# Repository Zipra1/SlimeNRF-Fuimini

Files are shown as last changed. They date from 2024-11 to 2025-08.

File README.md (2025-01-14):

# SlimeNRF-Fuimini-PCB

Supermini-based PCB for nRF flavoured SlimeVR body trackers.

Schematic based off [SlimeVR-Tracker-nRF-PCB](https://github.com/SlimeVR/SlimeVR-Tracker-nRF-PCB)

Cat drawing on the PCB by [my amazing beatuifiul wife](https://www.tumblr.com/circlegirl?source=share)

Detailed README.md files are in folders.

## i sell these! you can find me here https://discord.gg/vpxSHmUSXH or email me at fui@macroplastics.ca
Fill out the order request form [here.](https://docs.google.com/forms/d/e/1FAIpQLScfmLpJ5HOZYNQvP2Ge38ma0vZgONCtincXcMHiBUueDEZLeg/viewform?usp=header)
Photos and user-friendly details in the spreadsheet. Website coming eventually.
Curious where prices come from? View the entire spreadsheet [here.](https://docs.google.com/spreadsheets/d/1XSO24xmqJCDWiKMqtOlyQpGnMuTRnx9r1LJr4mPH8TY/edit?usp=sharing)

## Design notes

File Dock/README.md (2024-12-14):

## Charging dock
Currently this repo only contains the files for a dock with 6 trackers. Due to technical limitations I can't provide a parametric file. I will add 5,6,7,8,9,& 10 docks later.\
If you want a dock with # of trackers that isn't included here, feel free to [contact me on discord](https://discord.gg/vpxSHmUSXH) for the files.\
Spots for rubber feet fit standard 6mm adhesive non-slip rubber feet.\
Wall mounts are for generic 1¼" drywall screws.\
Uses [Treedix USB Type-C Breakout Board](https://www.amazon.ca/gp/product/B096M2HQLK) as the USB C input. This isn't a custom PCB because only one is required per dock, it's cheaper to order these than a custom pcb in small quantities.\

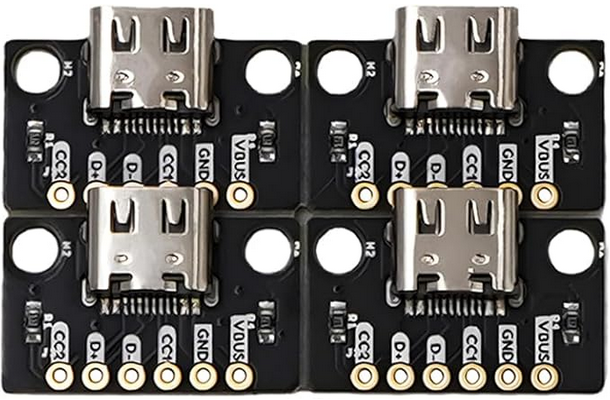
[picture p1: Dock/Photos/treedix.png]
Treedix USB Type-C Breakout Board
\

* The .3mf is for Orca Slicer. I print with a Bambu Labs P1S.

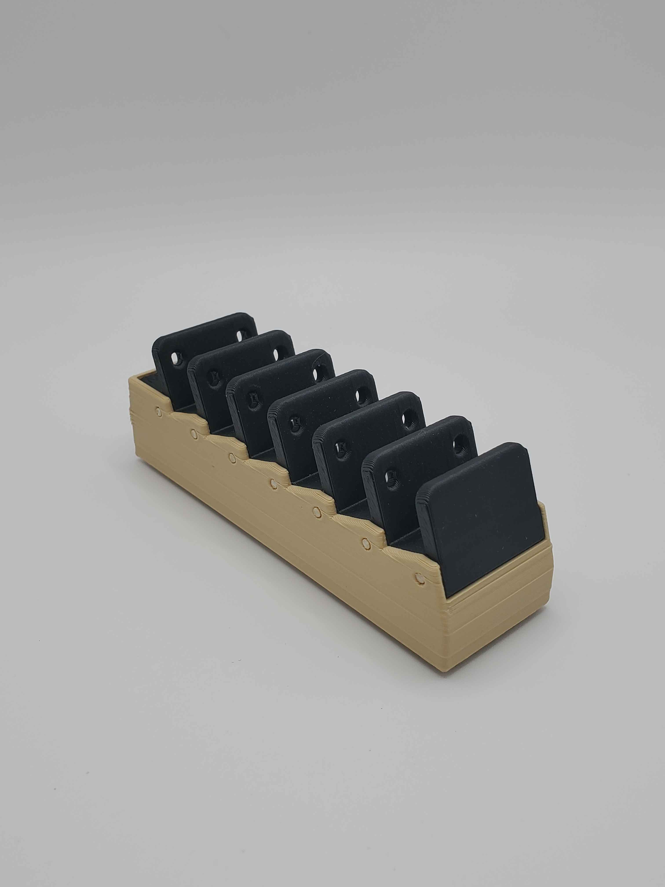
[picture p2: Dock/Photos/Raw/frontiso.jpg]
Front Photos
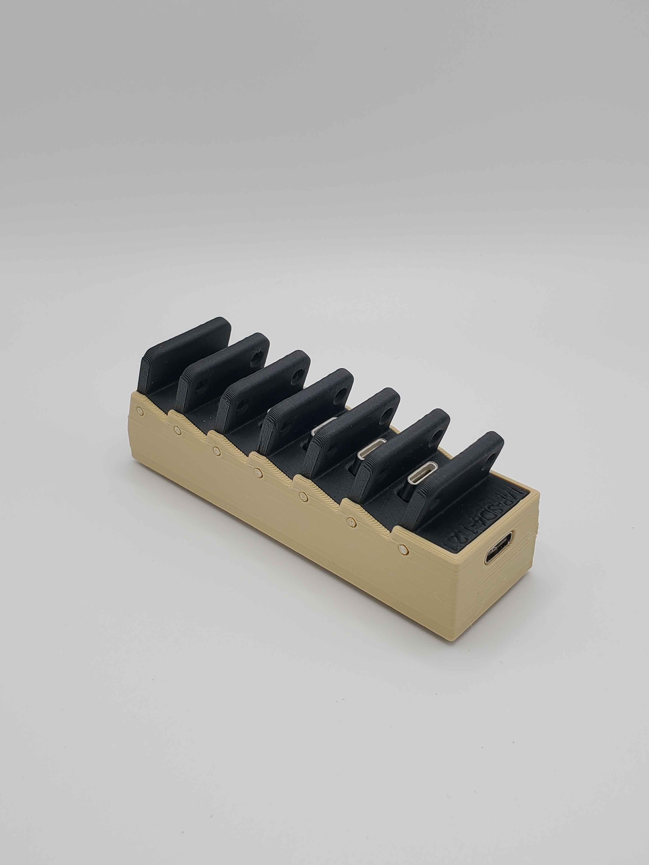
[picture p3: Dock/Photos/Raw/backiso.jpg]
Back
 \
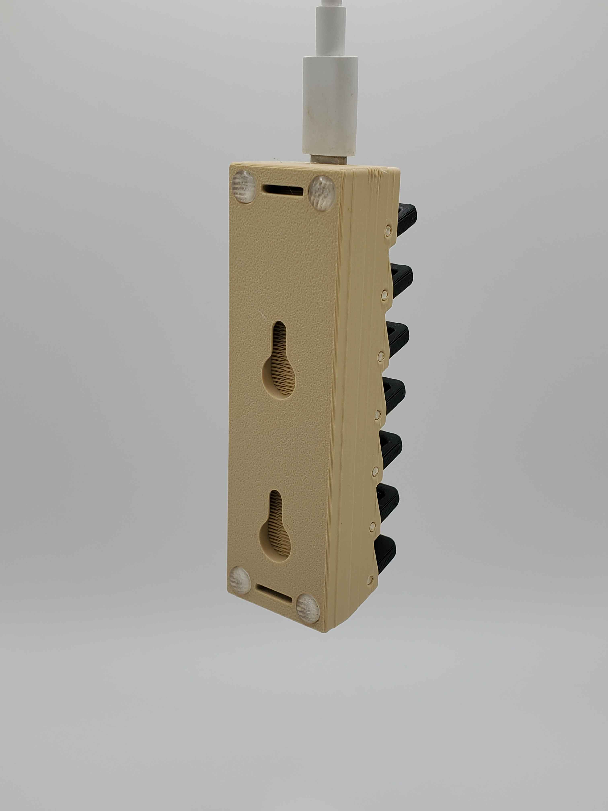
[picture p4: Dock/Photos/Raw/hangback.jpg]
Bottom
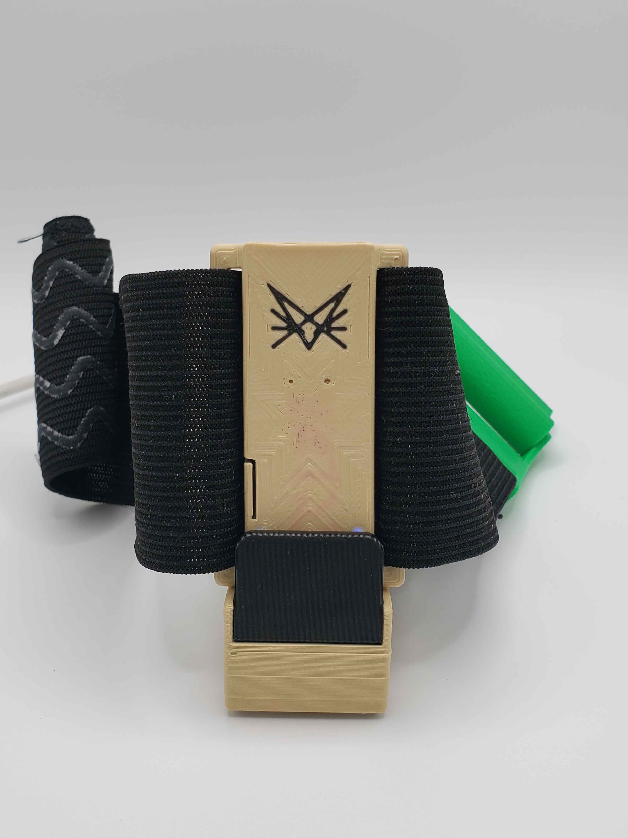
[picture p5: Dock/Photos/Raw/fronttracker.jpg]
Charging
 \

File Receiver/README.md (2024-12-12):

## This case is for the EByte nrf52840 dongle
Model number E104-BT5040U. Looks like this:
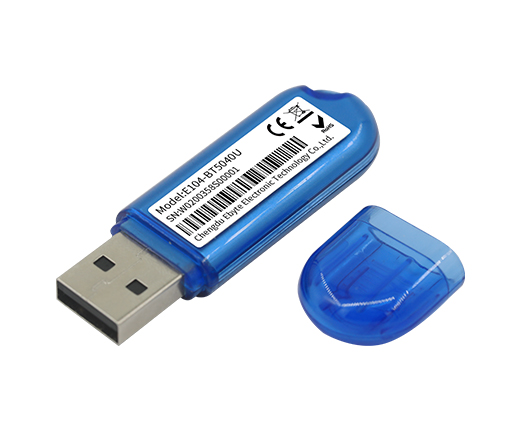
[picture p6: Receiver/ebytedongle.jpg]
ebyte dongle


New dongle case (without multimaterial) looks like this:
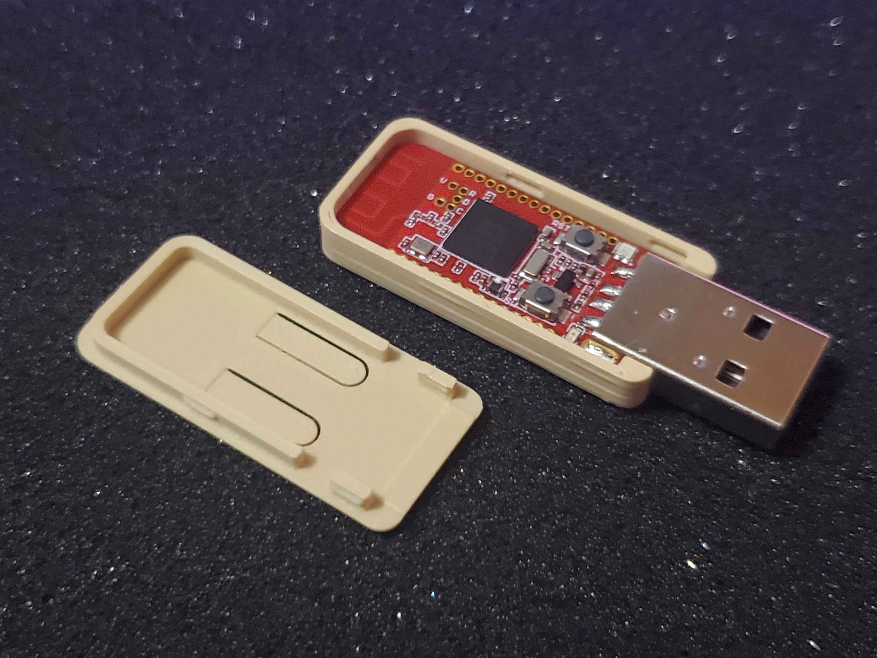
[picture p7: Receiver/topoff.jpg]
printed, top off

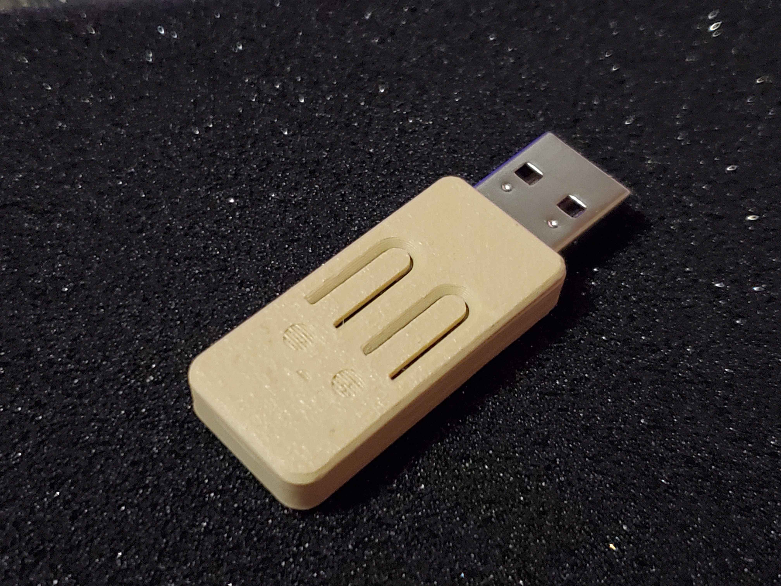
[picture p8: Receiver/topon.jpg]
printed, top on


its a bunny! :3
-# i know this folder is super disorganized. sorry :3

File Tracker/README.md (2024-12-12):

## some things to take note of!
These are pretty hard to print compared to the receiver case. I recommend looking at the .3mf file. A multi-material printer with at least 2 materials is required for the light diffuser to function.
0.12mm layer height
Layer height modifier required to print properly
Thick bridges ON
* The .3mf is for Orca Slicer. I print with a Bambu Labs P1S.

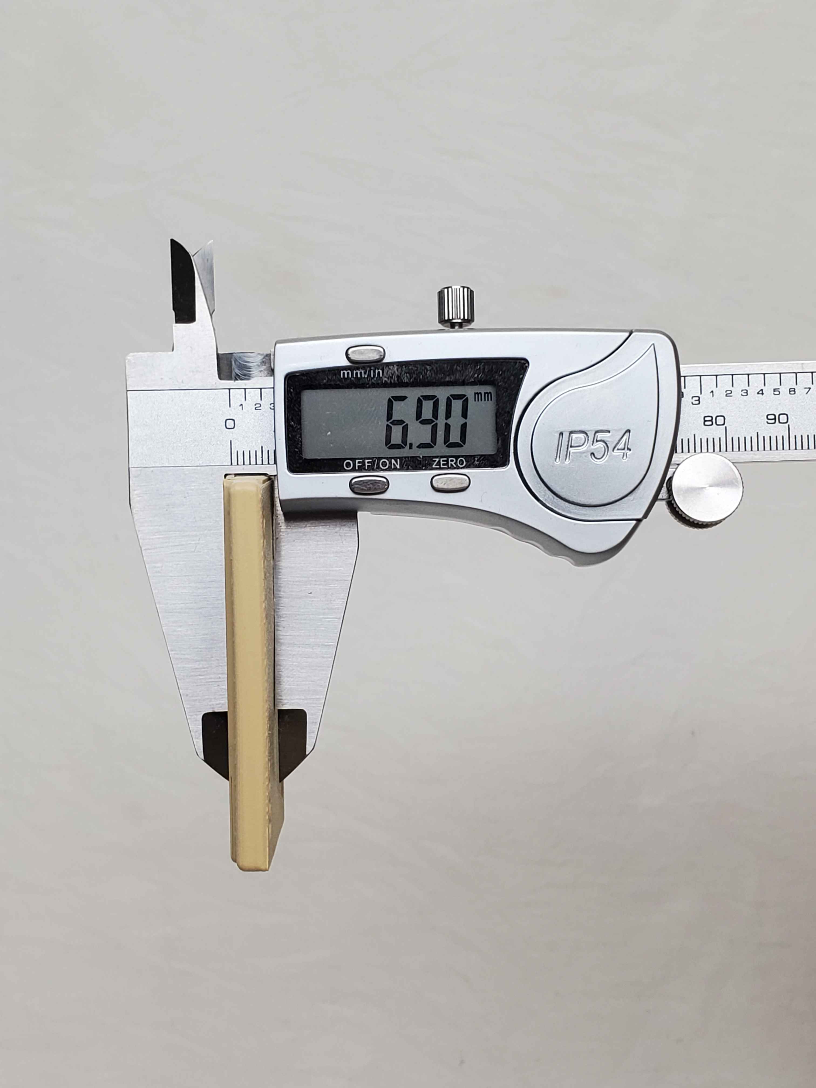
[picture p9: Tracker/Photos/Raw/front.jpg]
Front Photos

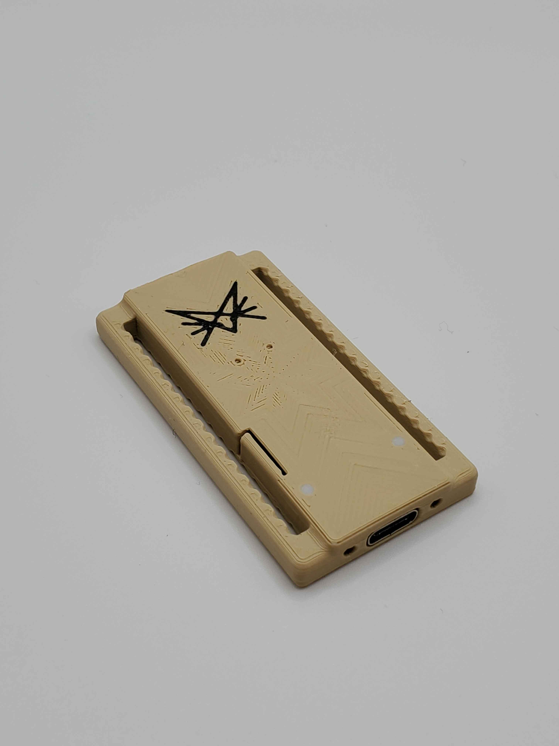
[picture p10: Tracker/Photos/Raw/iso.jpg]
Iso

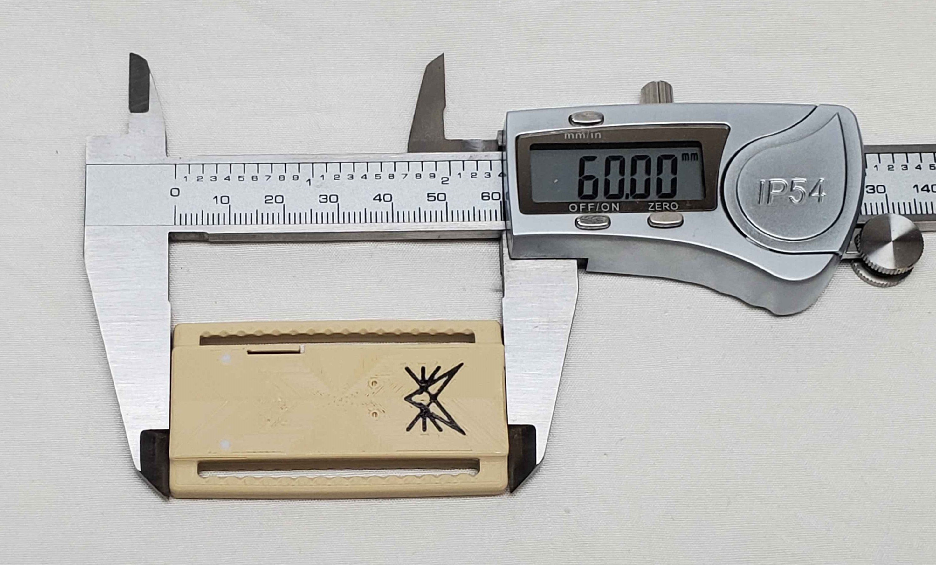
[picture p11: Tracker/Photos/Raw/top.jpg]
Top

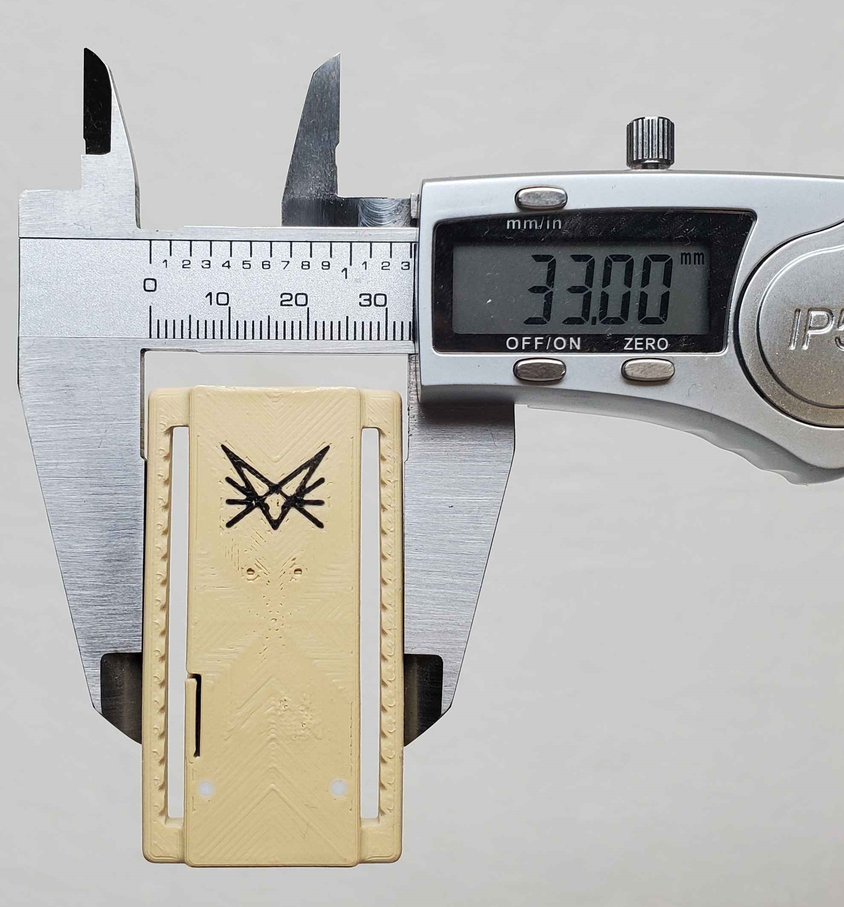
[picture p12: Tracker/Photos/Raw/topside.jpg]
Top side measurement


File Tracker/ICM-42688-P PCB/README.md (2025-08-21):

# This is currently NON-FUNCTIONAL
It is in the midst of an update to SPI, as well as some extra features. Please check out Commit `f3380db` for the currently functional version.

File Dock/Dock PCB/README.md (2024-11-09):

# Dock
The dock uses a "treedix" USB C breakout board instead of a custom PCB for the USB C, as I am not planning to make a large enough volume to justify having a separate b oard with USB C.

The dock is made of several individual PCB's so that they can be slanted in the dock, making it better for mounting on wall (even though really they'd be fine, it looks nicer like that)

Design is not final. I might abandon the slant idea if it's not worth it.

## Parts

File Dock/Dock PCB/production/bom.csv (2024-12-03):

Designator | Footprint | Quantity | Value | LCSC Part #
J1, J2 | PinHeader_1x04_P2.54mm_Vertical | 2 | DNP
U1 | Treedix USB Type-C | 1 | DNP
U2 | YTC-TC16S-128 | 1 | YTC-TC16S-128

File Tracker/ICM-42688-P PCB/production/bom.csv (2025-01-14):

Designator | Footprint | Quantity | Value | LCSC Part #
C2 | 0402 | 1 | 1uF | C14663
C3 | 0402 | 1 | 10nF | C14663
C4, C8 | 0402 | 2 | 100nF | C14663
C5 | 0402 | 1 | 10uF | C14663
C7 | 0402 | 1 | 2.2uF | C14663
R1, R2 | 0402 | 2 | 10k | C23162
R5 | 0402 | 1 | 200k | C23162
S1 | GT-TC020B-H035-L05 | 1 | GT-TC020B-H035-L05
TP1, TP2 | 2_4-1.5_3.5_1 | 2 | BCon
U2 | ICM-42688-P | 1 | ICM-42688-P
U3 | MMC5983MA | 1 | MMC5983MA
U4 | K3-1295S-E1 | 1 | K3-1295S-E1
X1 | OK252032.768KJBA4SL | 1 | ~

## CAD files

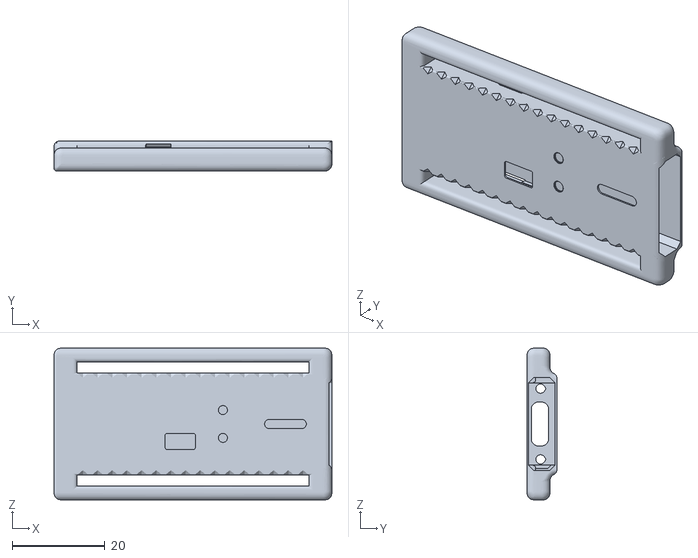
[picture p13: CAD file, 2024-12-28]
Tracker/3D Models/Main Body.STL
60.0 x 6.48 x 32.8

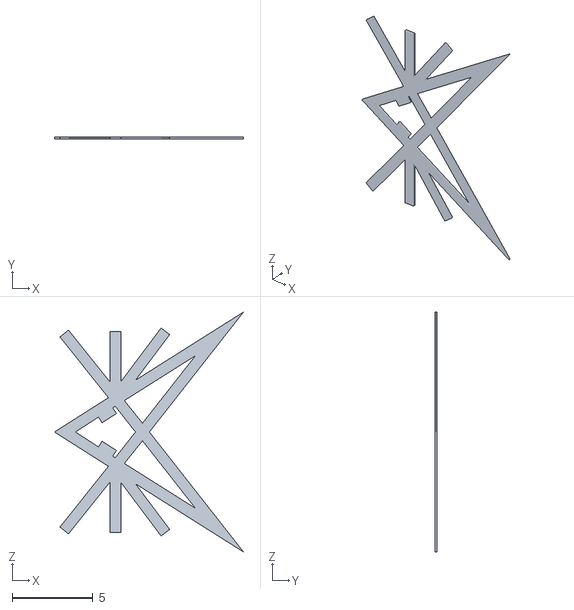
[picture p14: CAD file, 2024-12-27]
Tracker/3D Models/Main Body_Logo.STL
11.7 x 0.12 x 14.8

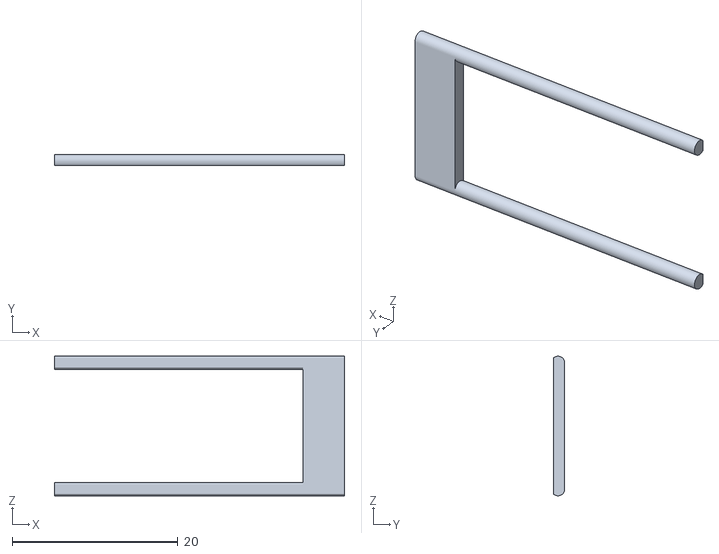
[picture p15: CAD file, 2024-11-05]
Tracker/3D Models/Disassembly tool.STL
35.0 x 1.37 x 16.9

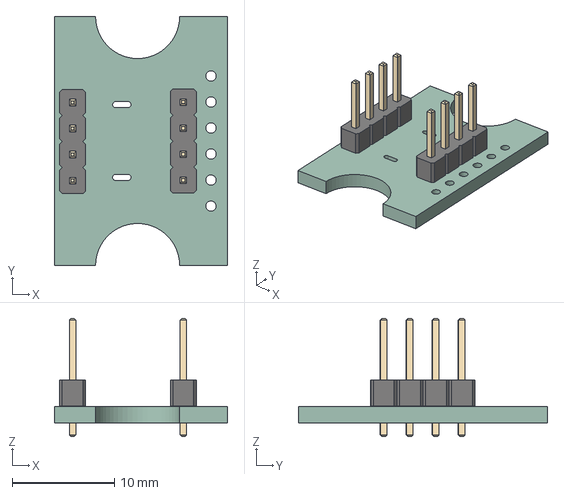
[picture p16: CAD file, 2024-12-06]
Dock/Dock PCB/SlimeV3-Dock.step
16.9 x 24.3 x 11.5 mm
PinHeader_1x04_P254mm_Vertical x 2
SlimeV3-Dock_PCB

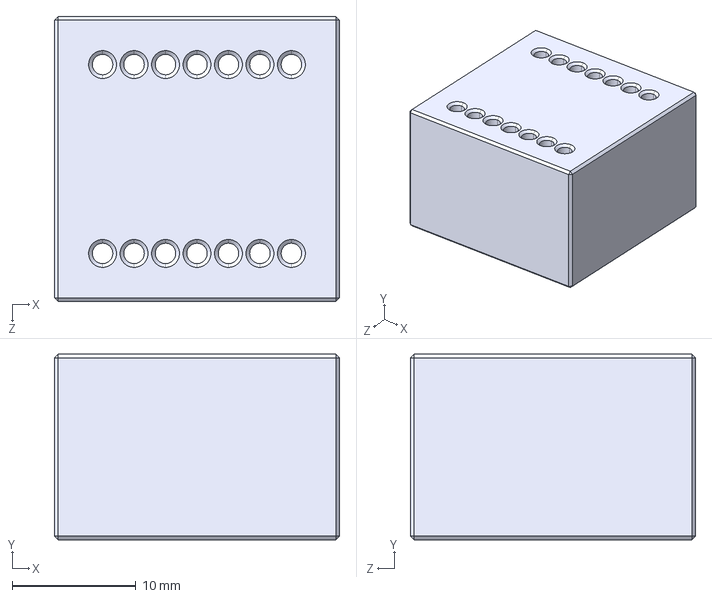
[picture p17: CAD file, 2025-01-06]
Jigs/Pogo pin testing block.STEP
23.0 x 15.0 x 23.0 mm

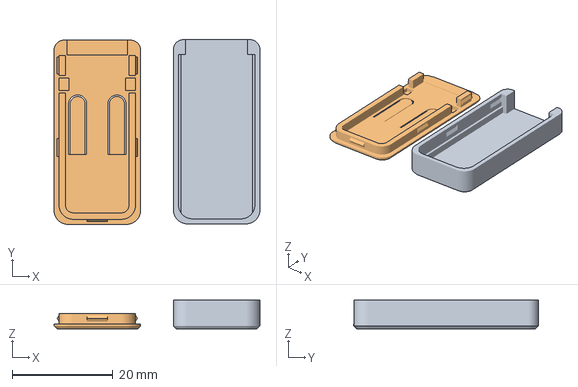
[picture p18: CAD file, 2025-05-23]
Receiver/ebyte.3mf
40.9 x 36.7 x 5.75 mm
nRF52840 EByte Button Case Bottom.STEP
nRF52840 EByte Button Case Top.STEP

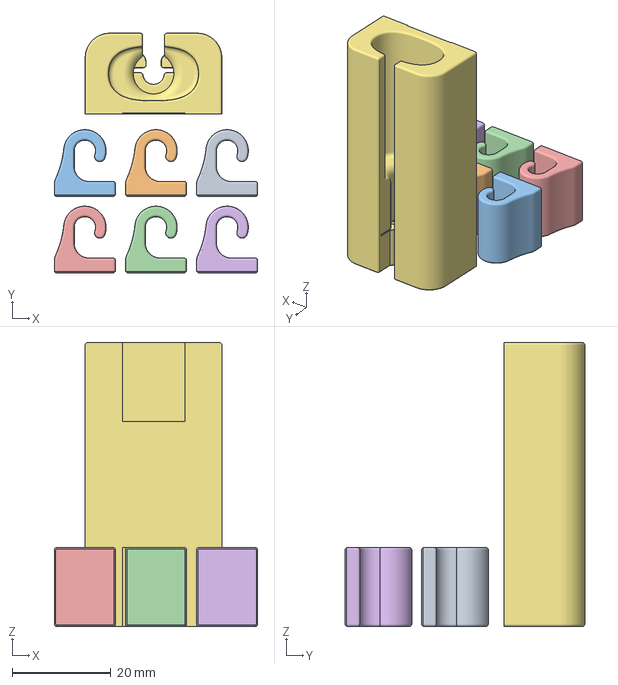
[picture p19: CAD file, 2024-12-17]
Receiver/Extension cable/Hook+mount.3mf
41.2 x 48.5 x 57.5 mm
Cable hook.STEP x 6
Ceiling mount.STEP

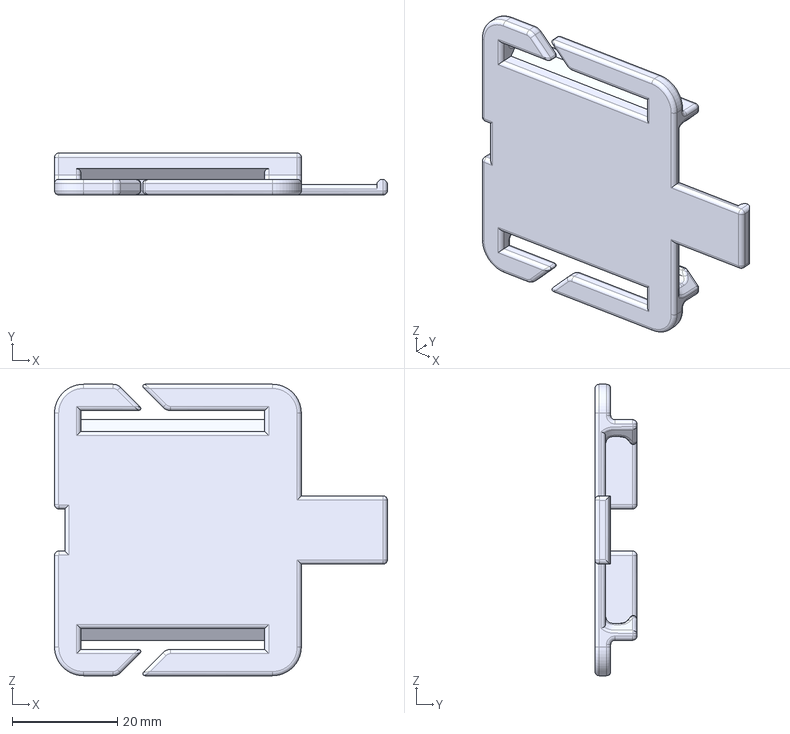
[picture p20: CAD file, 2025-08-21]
Straps/Chesty Mount Alt.STEP
63.4 x 8.00 x 55.5 mm

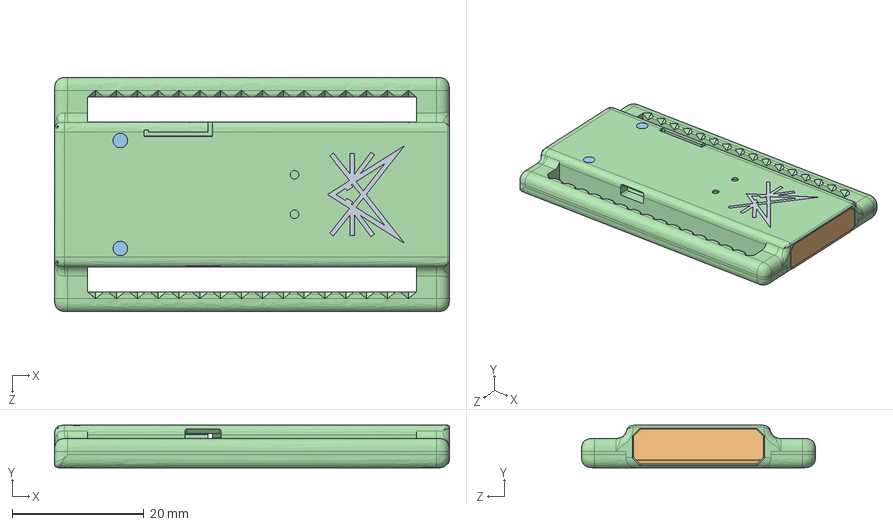
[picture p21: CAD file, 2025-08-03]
Tracker/3D Models/FuiminiCase.STEP
60.0 x 6.48 x 35.6 mm

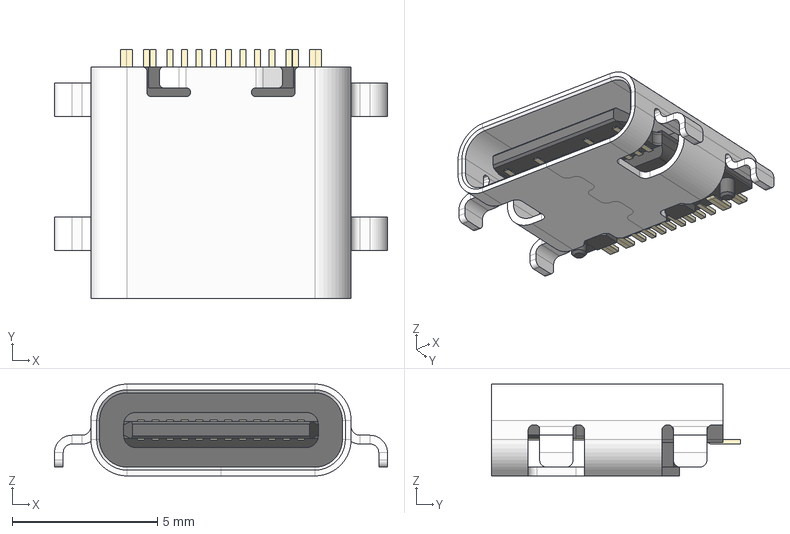
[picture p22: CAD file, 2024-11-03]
Tracker/ICM-42688-P PCB/HRO TYPE-C-31-M-14.step
11.5 x 8.56 x 3.16 mm
Shroud
Plastic Body & Connector

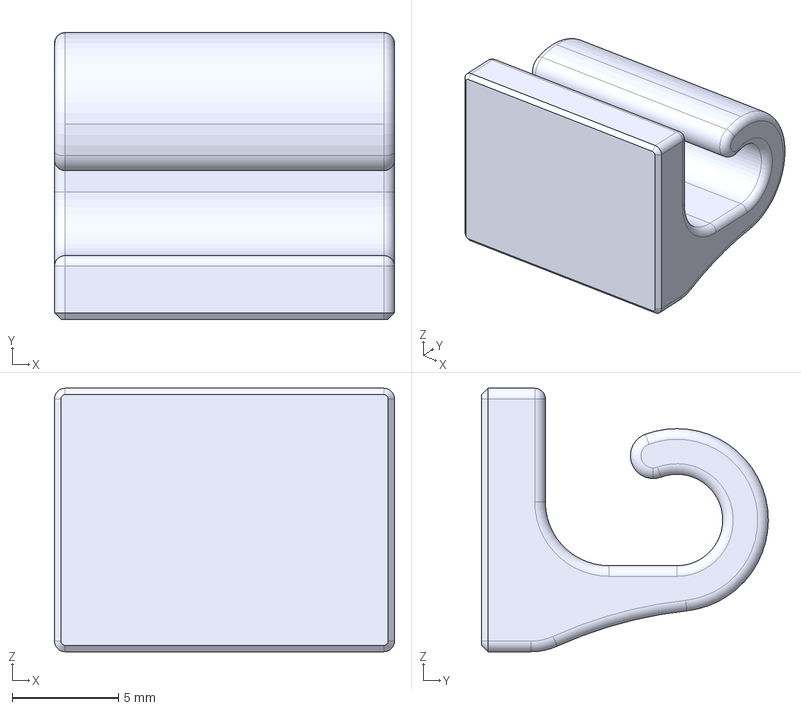
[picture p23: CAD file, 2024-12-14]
Receiver/Extension cable/Cable hook.STEP
16.0 x 13.5 x 12.4 mm

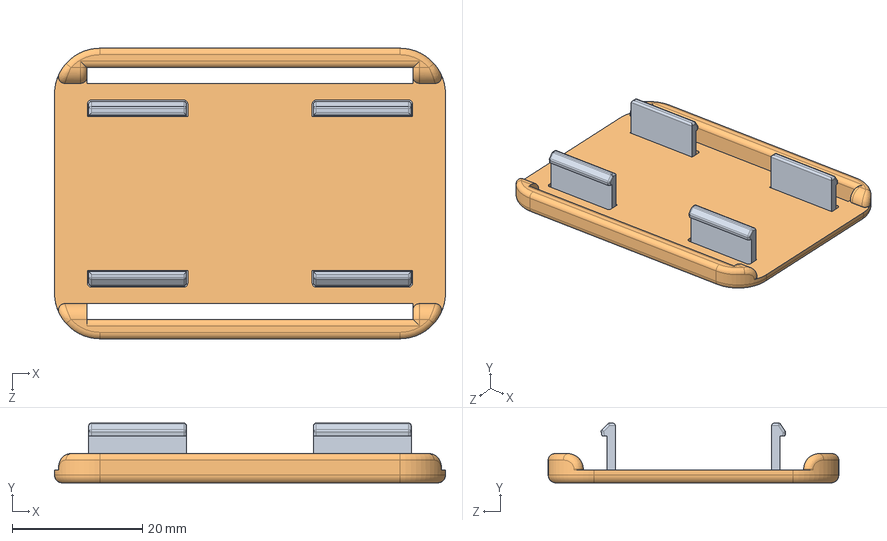
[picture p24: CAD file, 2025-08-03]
Straps/Chest clip.STEP
60.0 x 9.18 x 44.6 mm

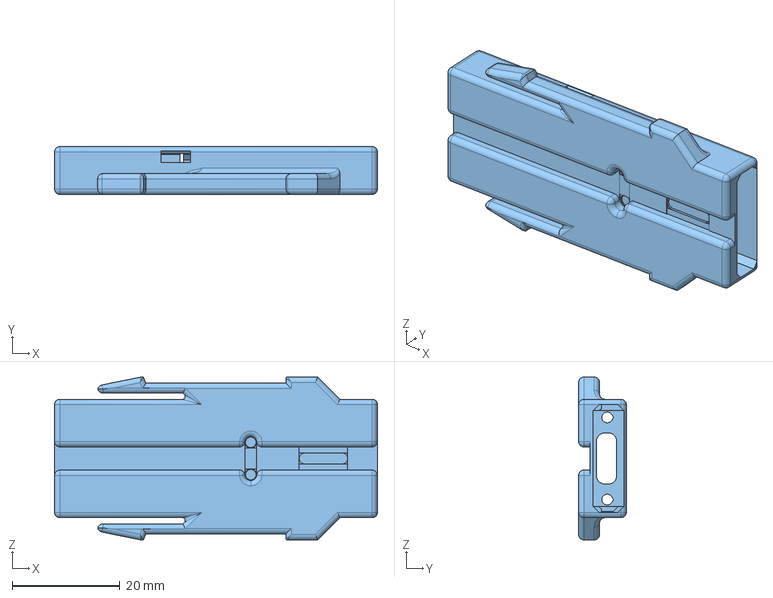
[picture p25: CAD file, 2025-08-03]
Tracker/3D Models/FuiminiCase-GoPro.STEP
60.0 x 8.88 x 30.3 mm

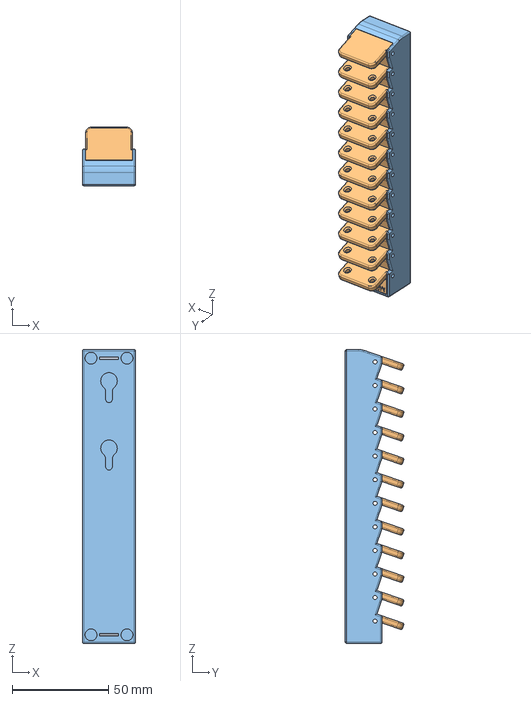
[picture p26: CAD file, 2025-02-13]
Dock/3D Models/SV4 dock (11).STEP
27.7 x 30.5 x 152.7 mm

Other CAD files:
Receiver/Extension cable/Ceiling mount.STEP
Straps/Cam Lock Shoulder Strap.STEP
Tracker/3D Models/Case.3mf
Dock/3D Models/SV4 dock (10).STEP
Dock/3D Models/SV4 dock (5).STEP
Dock/3D Models/SV4 dock (7).STEP
Dock/3D Models/SV4 dock (8).STEP
Dock/3D Models/SV4 dock.3mf
Dock/3D Models/SV4 dock.STEP
Jigs/Pogo pin testing block.3mf
Receiver/nRF52840 EByte Button Case Bottom.STEP
Receiver/nRF52840 EByte Button Case Top.STEP
Straps/Cam Lock Shoulder Strap Back Triangle.STEP
Straps/Chesty Mount.STEP
Straps/Velcro strap quick release.3mf
Straps/Velcro strap quick release.STEP
Tracker/3D Models/Calibration Jig.STEP
Tracker/3D Models/Debug Jig.STL
Tracker/3D Models/End Cap.STL
Tracker/3D Models/Light Diffuser.STL
Tracker/3D Models/Pin cutting jig.STL
Tracker/3D Models/USB_type_C_smd_24p.stp

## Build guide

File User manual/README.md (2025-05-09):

## Most human-readable version is in the Individual Pages folder.
The PDF files are a printable booklet, for printers that can only print on one side and have the paper feed on the back.
The booklet pdf's are made using https://online2pdf.com/create-booklet-flipbook

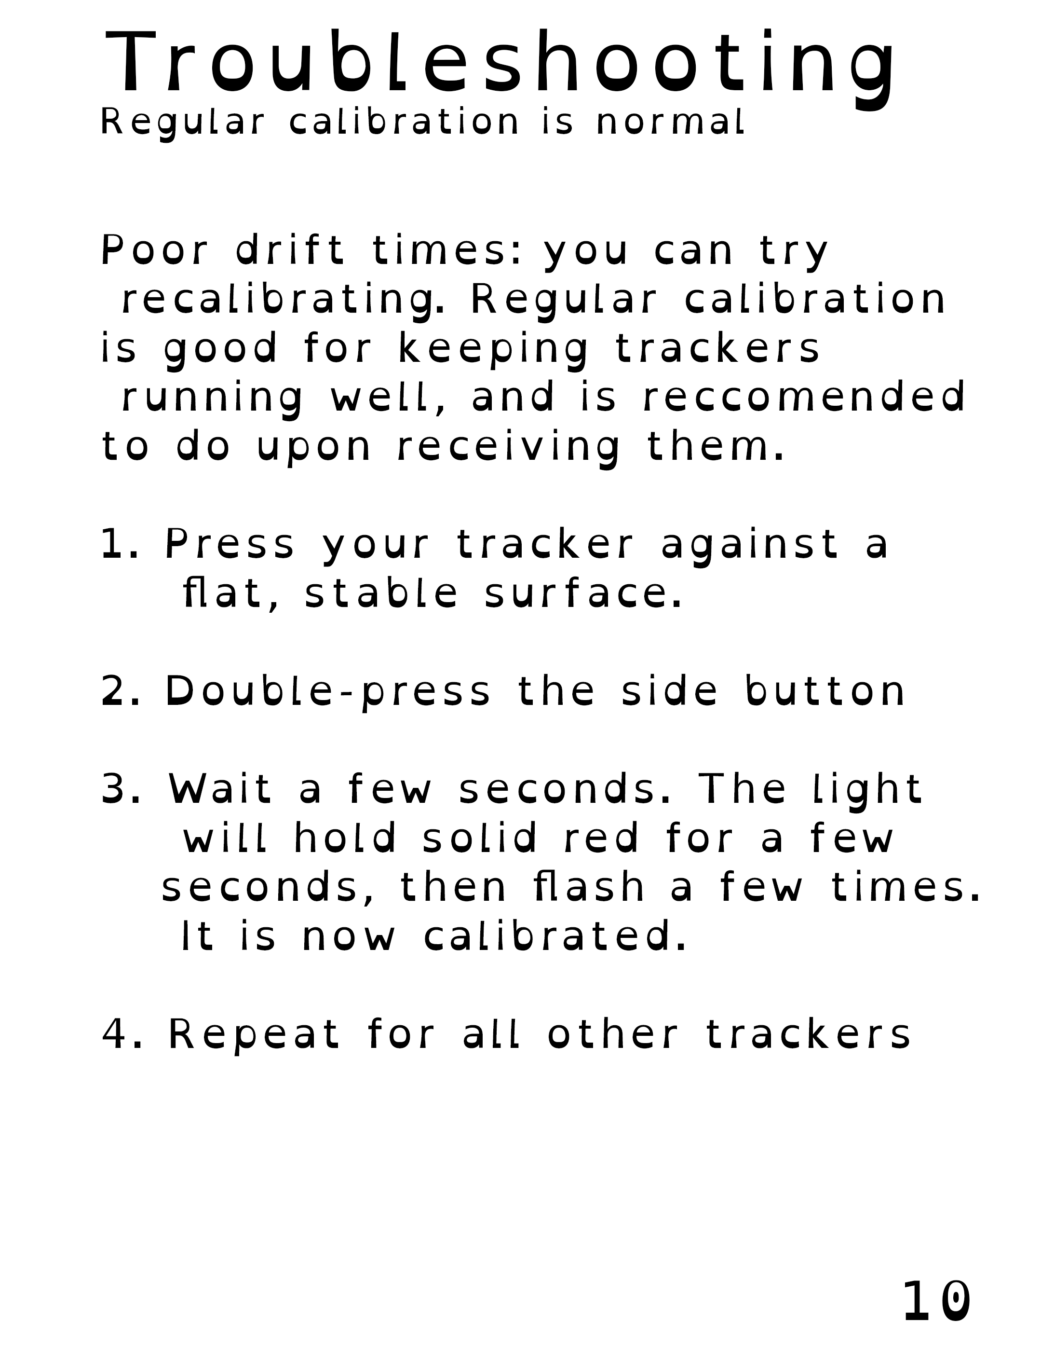
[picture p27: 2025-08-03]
User manual/Individual pages/L.png

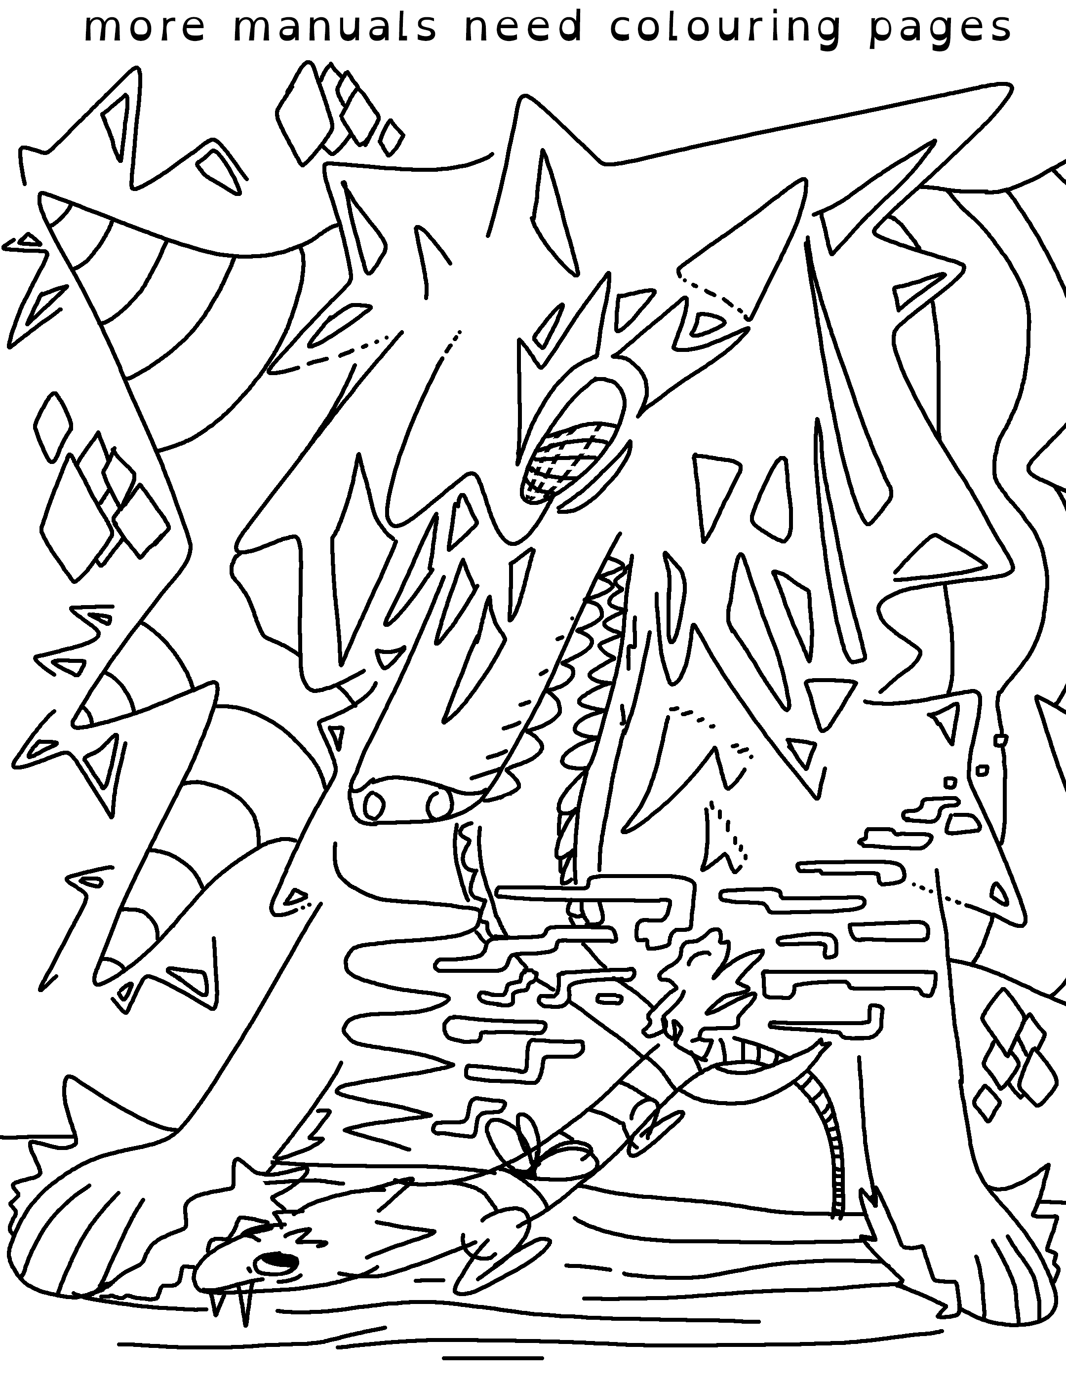
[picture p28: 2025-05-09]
User manual/Individual pages/S.png

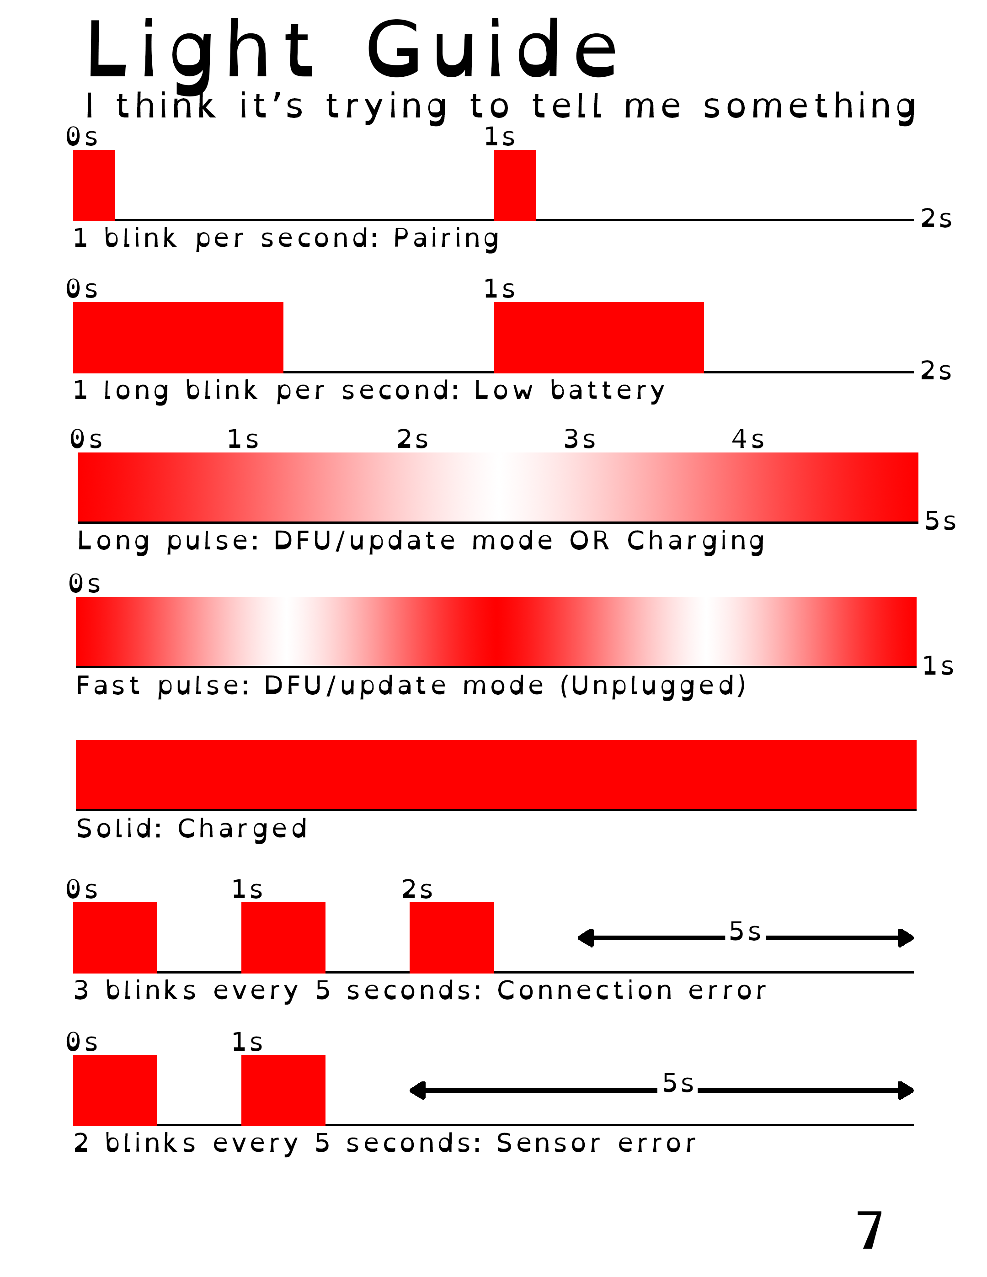
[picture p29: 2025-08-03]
User manual/Individual pages/I.png

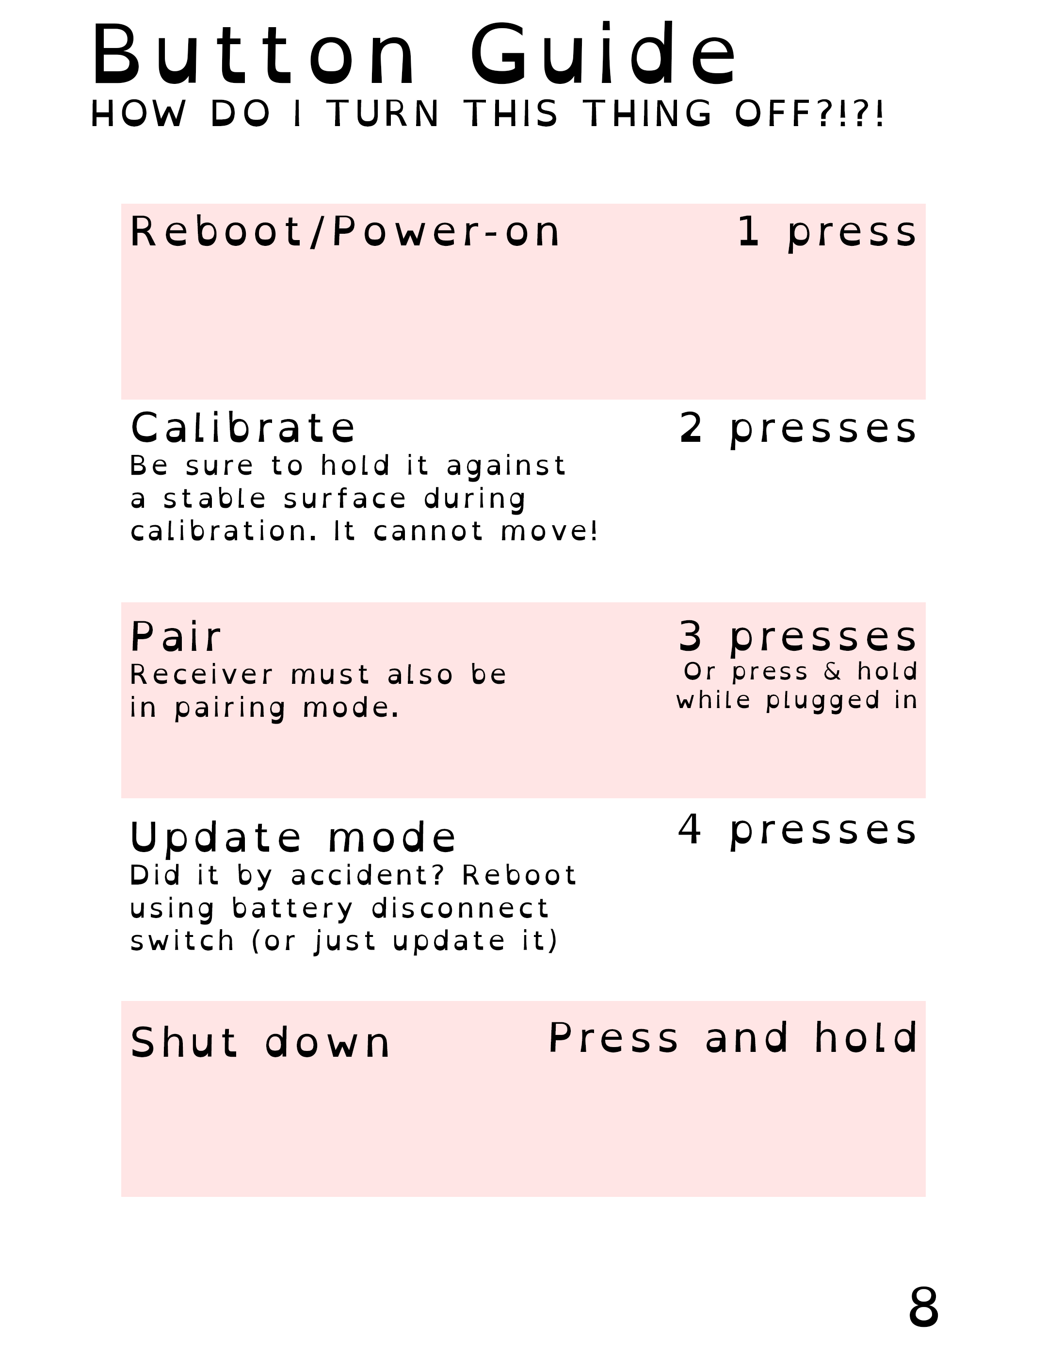
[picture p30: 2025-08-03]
User manual/Individual pages/J.png

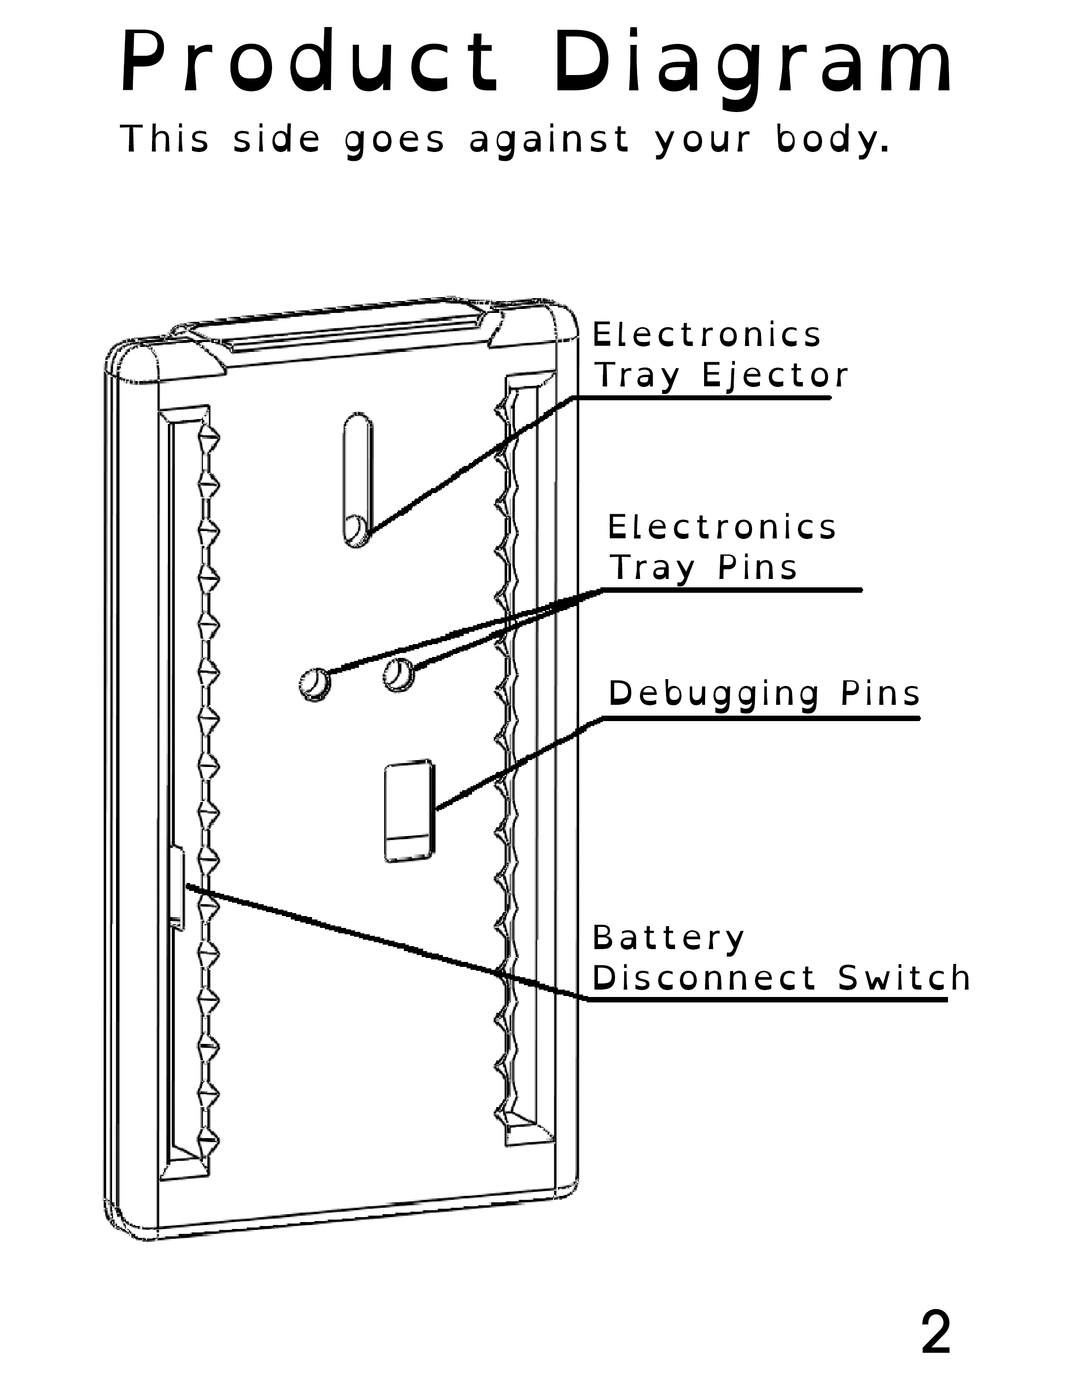
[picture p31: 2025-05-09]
User manual/Individual pages/D.png

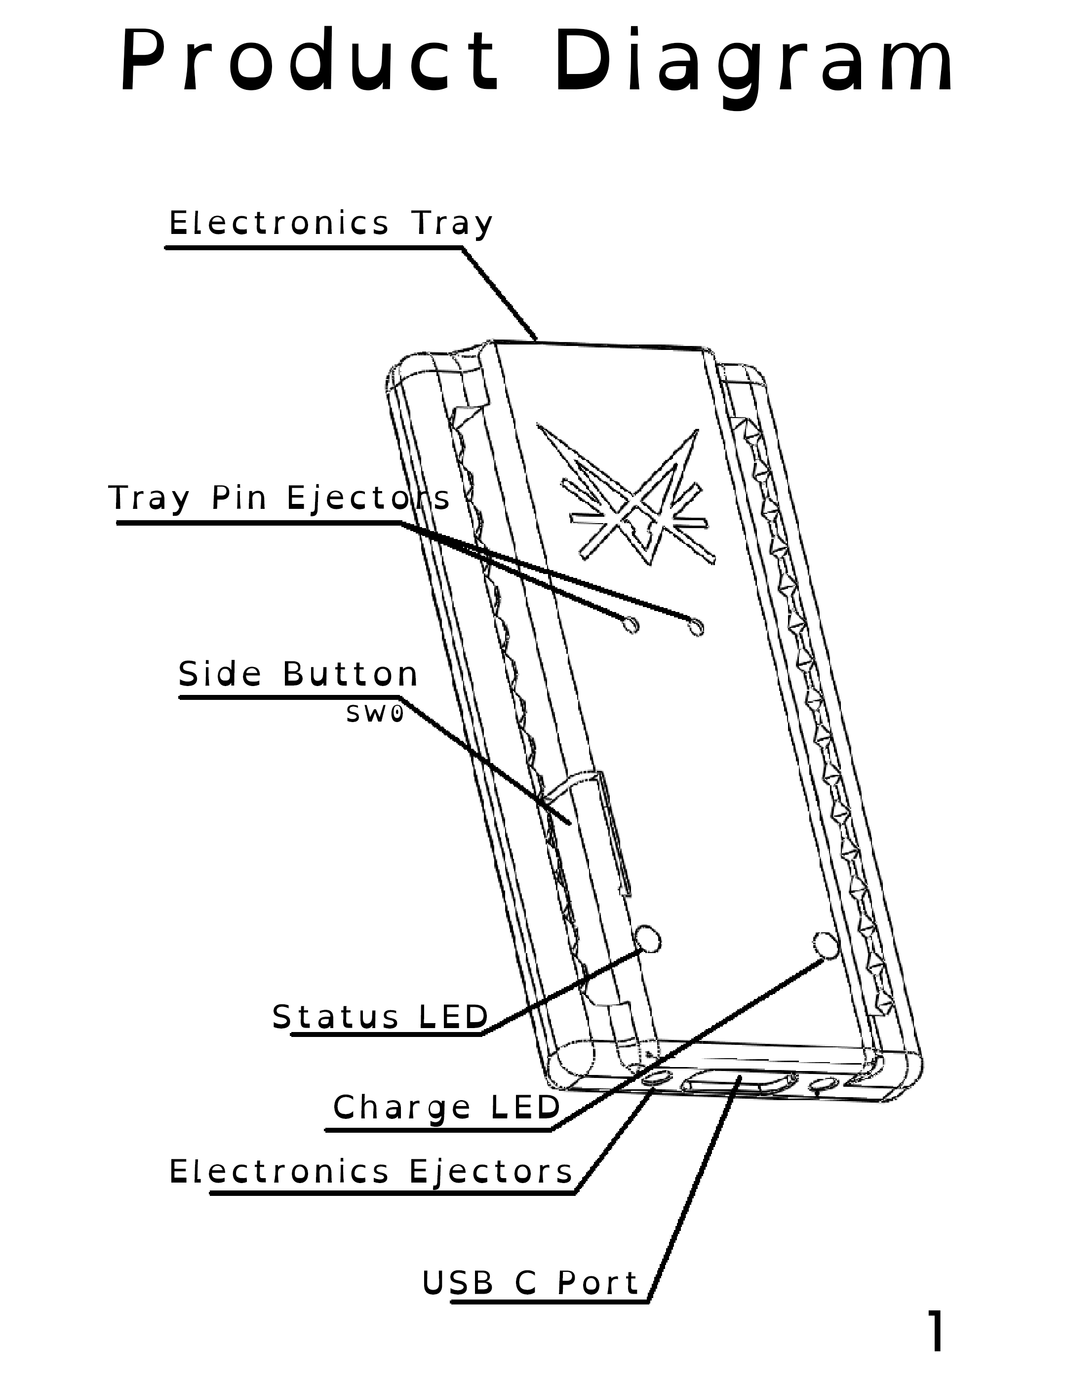
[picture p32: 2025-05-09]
User manual/Individual pages/C.png

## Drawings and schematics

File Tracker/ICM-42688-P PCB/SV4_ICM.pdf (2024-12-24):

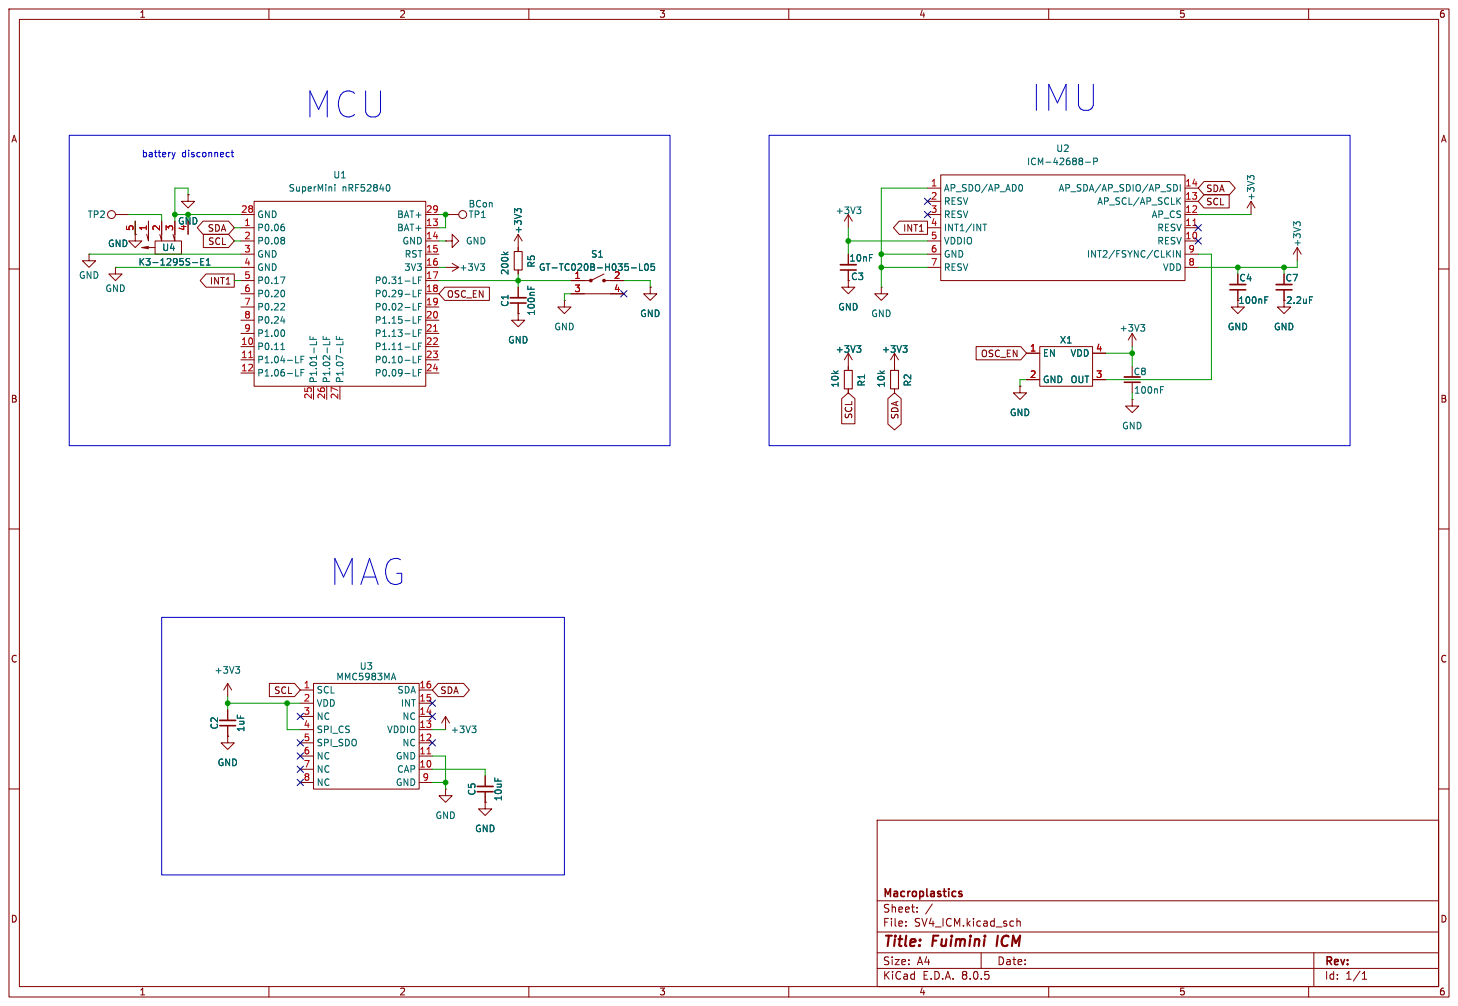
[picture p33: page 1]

Id: 1/1 Title: Fuimini ICM

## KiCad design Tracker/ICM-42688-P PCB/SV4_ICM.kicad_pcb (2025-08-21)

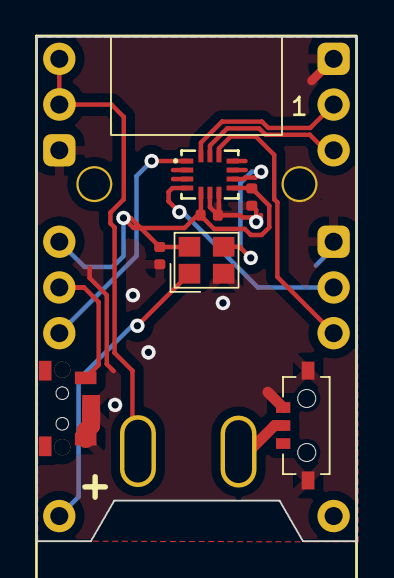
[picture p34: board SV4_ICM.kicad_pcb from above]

Board: 2 copper layers, 17.8 x 28.0 mm, 10 parts (0 on the bottom side), 12 nets.

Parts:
C3, C4, C8: 100nF; C_0402_1005Metric
S1: GT-TC020B-H035-L05
TP1, TP2: BCon; 2_4-1.5_3.5_1
U1: SuperMini nRF52840; SuperMini_nRF52840_AH_USBdn
U2: ICM-42688-P
U4: K3-1295S-E1
X1: OK252032.768KJBA4SL

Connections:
+3V3: C3.2, C4.2, C8.2, U1.16 (3V3), U2.5 (VDDIO), U2.8 (VDD), X1.4 (VDD)
CLK: U2.9 (INT2/FSYNC/CLKIN), X1.3 (OUT)
CS: U1.6 (P0.20), U2.12 (AP_CS)
GND: C3.1, C4.1, C8.1, S1.2, S1.3, U1.4 (GND), U1.14 (GND), U1.28 (GND), U2.6 (GND), U2.7 (RESV), U4.3, U4.4, U4.5, X1.2 (GND)
INT1: U1.5 (P0.17), U2.4 (INT1/INT)
unnamed: TP1.1, U1.13 (BAT+), U1.29 (BAT+)
unnamed: TP2.1, U4.2
unnamed: S1.1, U1.17 (P0.31-LF)
OSC_EN: U1.22 (P1.11-LF), X1.1 (EN)
SCL: U1.2 (P0.08), U2.13 (AP_SCL/AP_SCLK)
SDA: U1.1 (P0.06), U2.14 (AP_SDA/AP_SDIO/AP_SDI)
SDO: U1.18 (P0.29-LF), U2.1 (AP_SDO/AP_AD0)

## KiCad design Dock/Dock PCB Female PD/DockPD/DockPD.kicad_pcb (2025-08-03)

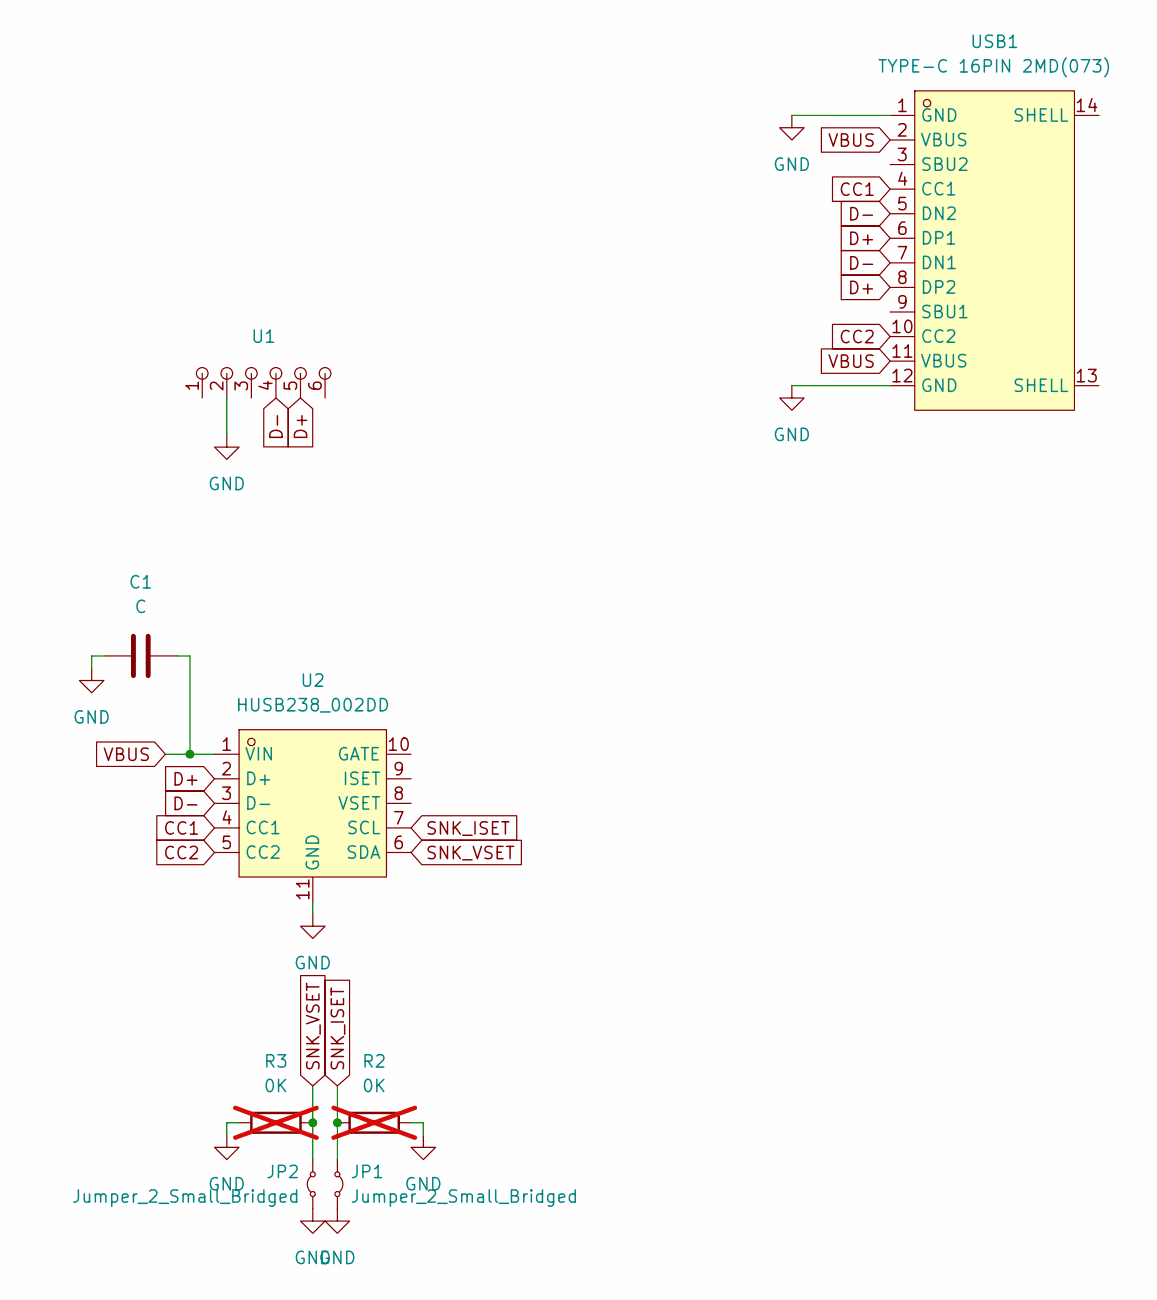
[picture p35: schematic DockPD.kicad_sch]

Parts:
C1: C; C_0402_JLC
JP1, JP2: Jumper_2_Small_Bridged; SolderJumper-2_P1.3mm_Open_TrianglePad1.0x1.5mm
R2, R3: 0K; R_Axial_DIN0204_L3.6mm_D1.6mm_P7.62mm_Horizontal; not fitted
U1: PinHeader_1x06_P2.54mm_Vertical
U2: HUSB238_002DD; DFN-10_L3.0-W3.0-P0.50-BL-EP2.5; LCSC Part C7471904
USB1: TYPE-C 16PIN 2MD(073); USB-C-SMD_TYPE-C-6PIN-2MD-073; LCSC Part C2765186

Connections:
CC1: U2.4 (CC1), USB1.4 (CC1)
CC2: U2.5 (CC2), USB1.10 (CC2)
D+: U1.5, U2.2 (D+), USB1.6 (DP1), USB1.8 (DP2)
D-: U1.4, U2.3 (D-), USB1.5 (DN2), USB1.7 (DN1)
GND: C1.1, JP1.2 (B), JP2.2 (B), R2.2, R3.1, U1.2, U2.11 (GND), USB1.1 (GND), USB1.12 (GND)
SNK_ISET: JP1.1 (A), R2.1, U2.7 (SCL)
SNK_VSET: JP2.1 (A), R3.2, U2.6 (SDA)
VBUS: C1.2, U2.1 (VIN), USB1.2 (VBUS), USB1.11 (VBUS)

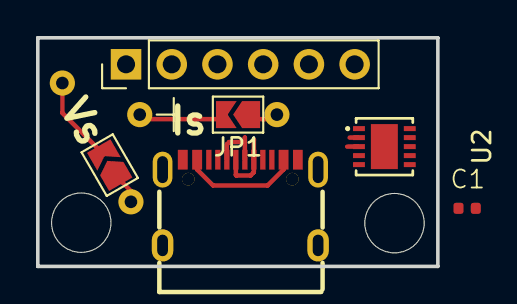
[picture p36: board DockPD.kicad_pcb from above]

Board: 2 copper layers, 22.2 x 12.7 mm, 8 parts (0 on the bottom side), 8 nets.

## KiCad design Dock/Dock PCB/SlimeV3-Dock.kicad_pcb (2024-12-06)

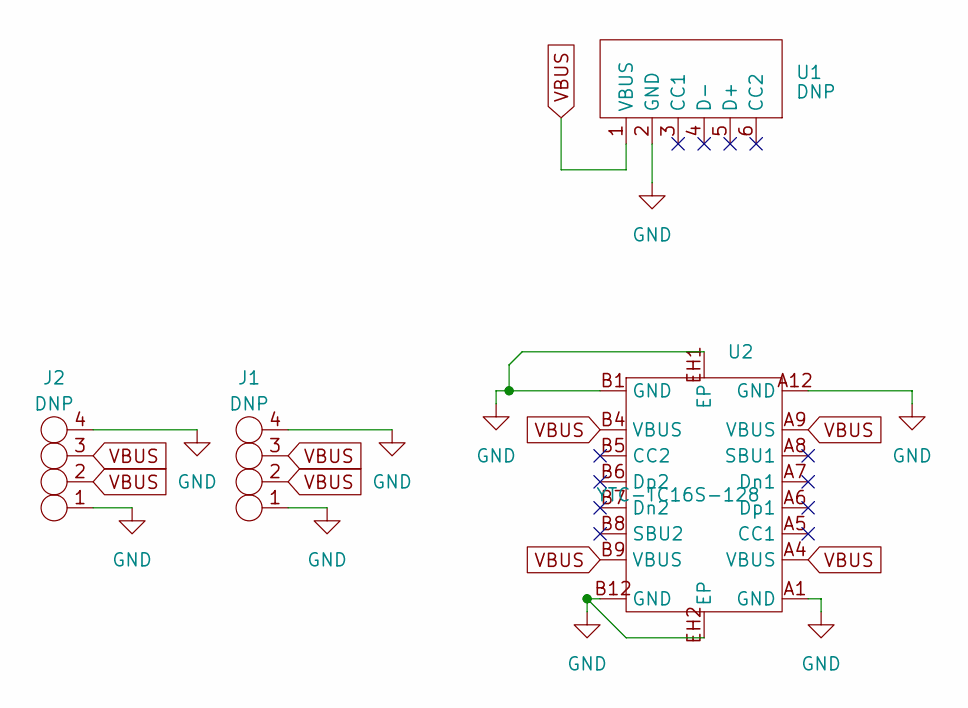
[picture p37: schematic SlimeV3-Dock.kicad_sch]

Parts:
J1, J2: DNP; PinHeader_1x04_P2.54mm_Vertical
U1: DNP; Treedix USB Type-C
U2: YTC-TC16S-128

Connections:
GND: J1.1, J1.4, J2.1, J2.4, U1.2 (GND), U2.A1 (GND), U2.A12 (GND), U2.B1 (GND), U2.B12 (GND), U2.EH1 (EP), U2.EH2 (EP)
VBUS: J1.2, J1.3, J2.2, J2.3, U1.1 (VBUS), U2.A4 (VBUS), U2.A9 (VBUS), U2.B4 (VBUS), U2.B9 (VBUS)

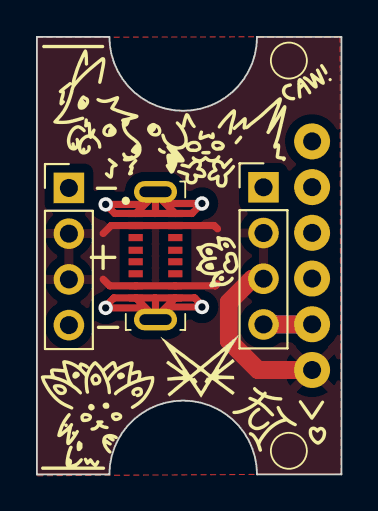
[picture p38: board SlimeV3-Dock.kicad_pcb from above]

Board: 2 copper layers, 16.9 x 24.3 mm, 4 parts (0 on the bottom side), 2 nets.

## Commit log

2024-11-03 Added all KiCad project files for board with ICM-42688-P + MMC5983MA
    [HRO TYPE-C-31-M-14.step, SV4_ICM.kicad_pcb, SV4_ICM.kicad_sch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]
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2024-11-03 i really said "added credit for pcb cat art" and then didnt. I did it this time for real.
2024-11-03 Added case stl and step file.
    [End Cap.STL, FuiminiCase.STEP, Main Body.STL]
2024-11-03 Improved printability for end cap
    [End Cap.STL, FuiminiCase.STEP]
2024-11-03 Flipped internals for better pin placement & printability
    [End Cap.STL, FuiminiCase.STEP, Main Body.STL]
2024-11-04 Case modifications: Filleted capped end. Added flex part for button. Adjusted end cap tolerances.
    [End Cap.STL, FuiminiCase.STEP, Main Body.STL]
2024-11-04 Added 3mf file for Orca Slicer. Improved bridged areas. Increased button travel space.
    [End Cap.STL, FuiminiCase.STEP, Main Body.STL]
2024-11-04 Fixed 3mf file. Reduced bridge distance. Fixed battery tray tolerances.
    [Case.3mf, End Cap.STL, FuiminiCase.STEP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]
2024-11-04 Added disassembly holes. Added USB C cutout. Thickened top layer by 0.12mm
    [Case.3mf, End Cap.STL, FuiminiCase.STEP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]
2024-11-04 Thickened light diffuser walls
    [Case.3mf, FuiminiCase.STEP, Main Body.STL]
2024-11-04 Added receiver case files. Restructured 3d models
    [Case.3mf, End Cap.STL, FuiminiCase.STEP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]
2024-11-04 Fixed 3d model folder deletion. Oops :3
    [Case.3mf, End Cap.STL, FuiminiCase.STEP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]
2024-11-04 - Added PCB push hole for easier disassembly - Increased pin push hole for SIM tools - Added disassembly slide to release battery tray - Added i2c pullups... I can't believe I forgot those. I already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
    [Case.3mf, End Cap.STL, FuiminiCase.STEP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]
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2024-11-05 - Added second PCB push hole to even pressure while disassembling - Tightened pin tolerances - Increased battery tray length to double as an assembly tool and board stabilizer - Added logo on tracker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
    [Case.3mf, Disassembly tool.STL, End Cap.STL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]
2024-11-05 - Flipped internals. Again - Pushed pins toward center to take advantage of battery shape
    [Case.3mf, End Cap.STL, FuiminiCase.STEP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]
2024-11-05 - Flipped internals. Again - Pushed pins toward center to take advantage of battery shape - Fixed button deflector - Lowered USB C cutout by 0.1mm
    [End Cap.STL, FuiminiCase.STEP, Main Body.STL]
2024-11-05 - Added .3mf missing from last commit.
    [Case.3mf]
2024-11-06 - Added light diffuser - Increased internal height by 0.12mm - Lowered USB C cutout by 0.1mm again - Decreased USB C cutout wall by 0.2mm, now 0.8mm thick
    [Case.3mf, End Cap.STL, FuiminiCase.STEP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]
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2024-11-07 - Added fillets on strap loops and back side top edge - Detached shaft from balls on the phallic-shaped symbol - Chamfered pin insert holes by 0.12mm for printability
    [Case.3mf, End Cap.STL, Main Body.STL]
2024-11-07 Updated .step file with changes from last
    [FuiminiCase.STEP]
2024-11-07 - Changed PCB "mirror" to 1mm NPTH, LED will shine through hole rather than reflect to side.
    [SV4_ICM.kicad_pcb]
2024-11-09 Added dock PCB files
    [SlimeV3-Dock.kicad_pcb, SlimeV3-Dock.kicad_sch, bom.csv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]
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2024-11-14 Added pin jig. Did not modify PCB, only opened for reference.
    [Pin cutting jig.STL, SlimeV3-Dock.kicad_pcb]
2024-11-14 Increased pin cutting jig width and length
    [Pin cutting jig.STL]
2024-11-17 Added supermini debug jig. Moved case button location to match PCB.
    [Case.3mf, Debug Jig.STL, Main Body.STL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]
2024-12-03 - Added dimensions to dock pcb - some other stuff probably that i forgot to write down
    [SV4_ICM.kicad_pcb, SV4_ICM.kicad_sch, SlimeV3-Dock.kicad_pcb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]
2024-12-06 - Increased body length by 2.2mm to allow more space for antenna. Was having signal strength issues. - Added 3d models for dock
    [Case.3mf, End Cap.STL, Light Diffuser.STL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]
2024-12-08 - Added battery disconnect switch on PCB - Fixed dock dimension issues - Removed stl files from dock folder. Just split the step file in your slicer. - Added 3mf file for dock models. Compatible with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
    [SV4 dock.3mf, SV4 dock.STEP, SV4_ICM.kicad_pcb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]
2024-12-09 - Fixed dock dimensions. Again
    [SV4 dock.STEP]
2024-12-11 - Fixed dock length issue - Added wall mount to dock - Added disassembly slots to dock
    [SV4 dock.3mf, SV4 dock.STEP]
2024-12-11 - Added spot for anti-slip feet on dock
    [SV4 dock.3mf, SV4 dock.STEP]
2024-12-11 - Improved dock print profile - Increased dock anti-slip feet insert depth - Increased dock repair slit width
    [SV4 dock.3mf, SV4 dock.STEP]
2024-12-12 - Reorganized file structure
    [Case.3mf, Debug Jig.STL, Disassembly tool.STL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]
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2024-12-14 - Added ceiling mount - Added cable hook
    [Cable hook.STEP, Ceiling mount.STEP]
2024-12-16 - Added logo to receiver model - Added link to pricing spreadsheet to readme
    [nRF52840 eByte Case_Top.STL, nRF52840 eByte Case_bottom.STL, nrf52480 eByte Case_L Eye.STL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]
2024-12-17 - Added extension cable hook - Reorganized receiver 3d files - Added calibration jig
    [Calibration Jig.STEP, Case.3mf, Hook+mount.3mf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]
2024-12-24 - Moved resistor to avoid conflict with USB C port - Added PDF of schematic for SlimeVR Marketplace listing
    [SV4_ICM.kicad_pcb]
2024-12-27 - Added slot in case to reach the battery disconenct switch - Decreased tolerances for case end cap
    [End Cap.STL, Light Diffuser.STL, Main Body.STL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]
2024-12-28 - Added cutout on bottom of case for debug pins - Added user manual
    [Case.3mf, Main Body.STL]
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2024-12-29 - added colouring page in user manual - added 7-tracker dock files - updated main readme - added readme for user manual folder
    [Case.3mf, SV4 dock (7).STEP, SV4 dock.3mf]
2024-12-31 - Added button functions page in user manual - Added 10-tracker dock STEP file
    [Case.3mf, SV4 dock (10).STEP, ebyte.3mf]
2025-01-06 - Added testing jig 3d model - Added folder for jigs - Removed debouncing capacitor from PCB, not needed.
    [Pogo pin testing block.3mf, Pogo pin testing block.STEP, SV4_ICM.kicad_pcb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]
2025-01-14 im ngl im really struggling with git rn sorry no commit message
    [SV4_ICM.kicad_pcb, bom.csv, designators.csv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]
2025-02-13 - Changed speed for top layers in 3mf file - Added more pages to manual - Added 11-tracker dock
    [Case.3mf, SV4 dock (11).STEP, SV4_ICM.kicad_pcb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]
2025-05-09 - Updated user manual - Added 5 and 8 docks - Added holyIOT dongle photos - Added Extension cable explanation.psd - Added light guide to user manual - Remade button guide in user manual - Switched us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
    [Case.3mf, SV4 dock (5).STEP, SV4 dock (8).STEP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]
2025-05-23 - Added maintenance page to user manual
    [Case.3mf, ebyte.3mf]
2025-05-24 - Added shoulder strap cam lock model
    [Cam Lock Shoulder Strap.STEP]
2025-05-25 - Added shoulder strap back triangle - Added quick disconnect for chest harness. Cause putting the harness on the dock would be rather cumbersome.
    [Cam Lock Shoulder Strap Back Triangle.STEP, Chest clip.STEP]
2025-08-03 - Edited user manual but i forgot what I put. why didnt i commit it when I did that? - Added more strap solutions
    [Cam Lock Shoulder Strap.STEP, Chest clip.STEP, Chesty Mount.STEP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]
2025-08-21 - Started updating pcb for spi, didn't ifnish lol use the last commit - Added
    [SV4_ICM.kicad_pcb, SV4_ICM.kicad_sch, Velcro strap quick release.3mf]
2025-08-21 - Added alternative chesty mount for slimmer fit but more difficult assembly.
    [Chesty Mount Alt.STEP]
2025-08-21 - Added PCB readme w/ warning
    [Velcro strap quick release.3mf]
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
